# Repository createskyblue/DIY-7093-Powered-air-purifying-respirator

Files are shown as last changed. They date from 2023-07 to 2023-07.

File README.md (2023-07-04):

# 佩奇和它的7093朋友 DIY 7093 PAPR

本项目将手把手教你搭建一个PAPR (动力送风过滤式呼吸器 Powered air-purifying respirator)，在保证暴力的效果同时，将成本控制在100人民币以内。

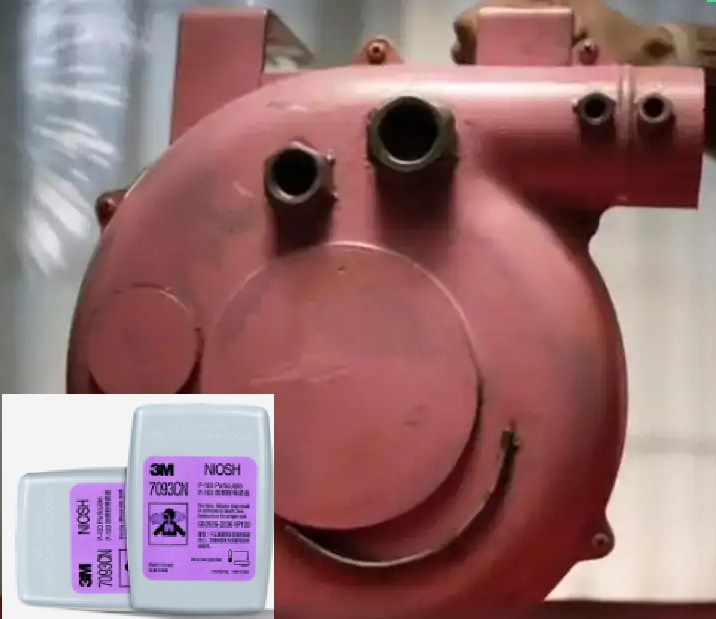
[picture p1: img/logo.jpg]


## 购物清单

你需要准备以下模块`风机和调速驱动`、`外壳`、`电源`、`气管 和 转接口`、`滤网耗材`
另外你还需要一些工具，比如`钳子`、`热熔胶枪`、`热熔胶`、`AB胶`、`705硅胶`、`热风枪`(可用`电钻`替代)、`一把长一点的螺丝刀`、`电烙铁`(可选，没有也不是不行)

### 滤网耗材

- 55￥ [3M7093CN滤毒盒](https://mobile.pinduoduo.com/transac_share_goods.html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)

### 核心风机以及驱动

- 7.8￥ [日本（Nidec）无刷蜗轮风机 DC14.4V 高速 扫地机器人吸尘风机](https://item.taobao.com/item.htm?spm=a1z09.2.0.0.9c0d2e8dZHmP4H&id=718315362174&_u=32d3muenbf90)
- 3.3￥ [带驱动无刷电机PWM调速板 DC8-24V无刷直流马达调速器](https://item.taobao.com/item.htm?spm=a1z09.2.0.0.9c0d2e8dZHmP4H&id=676307415459&_u=32d3muen34d2)

### 外壳

- 7￥ [透明盖防水盒室内外监控密封盒按钮盒仪表外壳塑料弱电防水接线盒 选择规格:F2BT 158*90*65](https://mobile.pinduoduo.com/transac_share_goods.html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) （👈请自行在拼多多平台搜索）

### 电源

- [DC002/005插座 5.5-1.3 1.35 2.0 2.1 2.5MM针DC电源充电接口母座: 购买一个](https://item.taobao.com/item.htm?spm=a21n57.1.0.0.4cd6523cXdlo5y&id=596616901501&ns=1&abbucket=0#detail)

- [DC电源线维修常用1米带线DC头 你需要购买两条规格不同的线，分别为`3.5X1.35` 和 `5.5X2.5/5.5X2.1`](D41729%26_wvx%3D10%26goods_share_id%3D2dae7d7162ddb39b16dcfcba66373f1e-3173614626821-468%26ordshr_page_sn%3D16999%26ordshr_entrance%3D1%26ordshr_page_el_sn%3D422363%26re_style%3Dtrue%26refer_share_id%3Dsma7jzfm31iuyaoho817l8i5vo41ig4b%26refer_share_uin%3D5ZL32O7MXE7ME6VAG3M3YTQVTA_GEXDA%26refer_share_channel%3Dmessage&_x_share_id=sma7jzfm31iuyaoho817l8i5vo41ig4b&refer_page_name=transac_share_goods&refer_page_id=889990_1688379440755_fuu6cvkwks&refer)

- [12V大容量空调服电池充电宝: 购买一个](https://mobile.pinduoduo.com/transac_share_goods.html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)

### 气管 和 转接口

- [呼吸机管路鱼跃通用管道配件22mm接口: 购买一个](https://mobile.yangkeduo.com/goods.html?goods_id=31158500752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)

- [波纹管接口 塑料软管接头 规格为：AD21.2 M20X1.5 购买两个，用于连接气管的两端](https://mobile.pinduoduo.com/transac_share_goods.html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)

#### 3M转接口现成方案（推荐）
- 8.8￥ [6200防毒面具喷漆防尘口罩5n11滤棉煤矿浓烟粉尘化工活性炭面罩]
https://mobile.pinduoduo.com/transac_share_goods.html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

#### 自己打印3M转接口（不推荐）
    自己打印的话容易出现各种问题，比如剪切力不过关，很容易拦腰折断；又或者气密性有问题。总之，如果你没有一定的3D打印经验，我不推荐你自己打印接口。

- [3M吸气阀片382 383 6893 6895呼吸阀3200 6200 7502面罩使用阀片: 6895垫圈 购买两个](https://item.taobao.com/item.htm?spm=a1z09.2.0.0.2ea82e8dwzGkS1&id=673407766279&_u=l2d3muen11c7)

## 3D模型
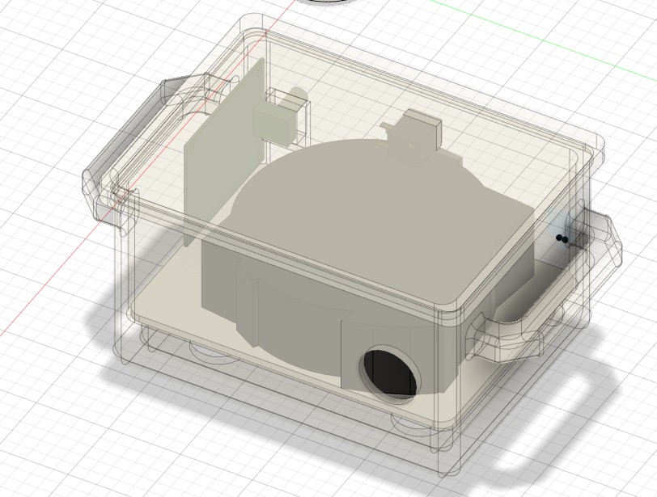
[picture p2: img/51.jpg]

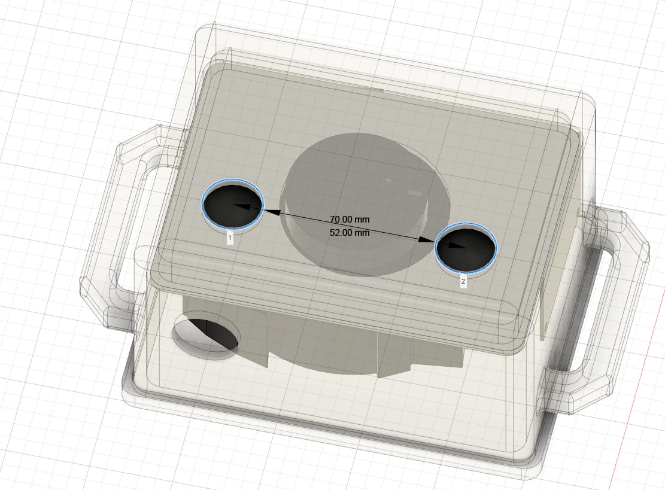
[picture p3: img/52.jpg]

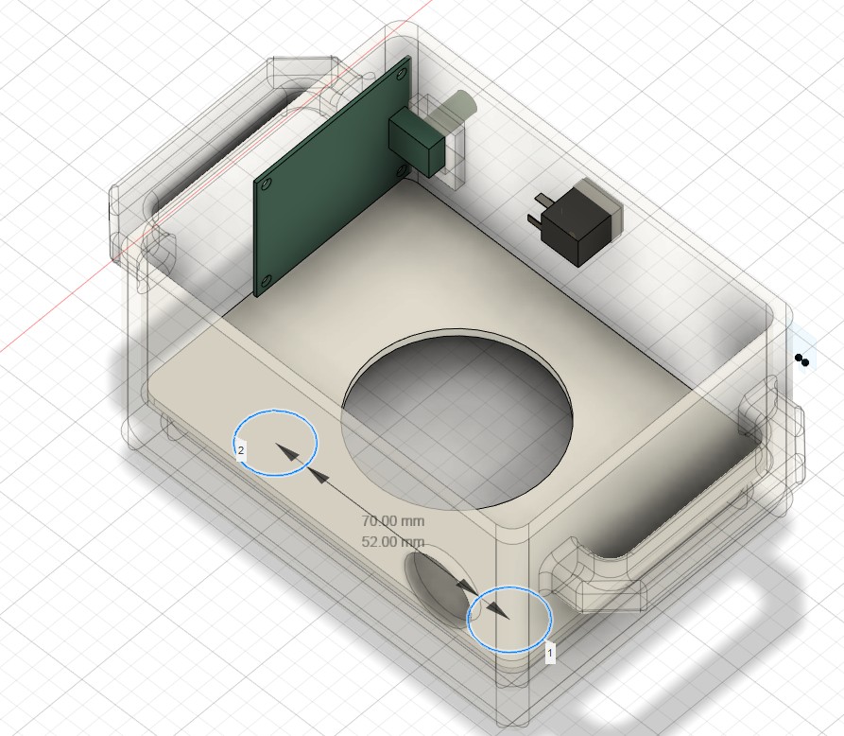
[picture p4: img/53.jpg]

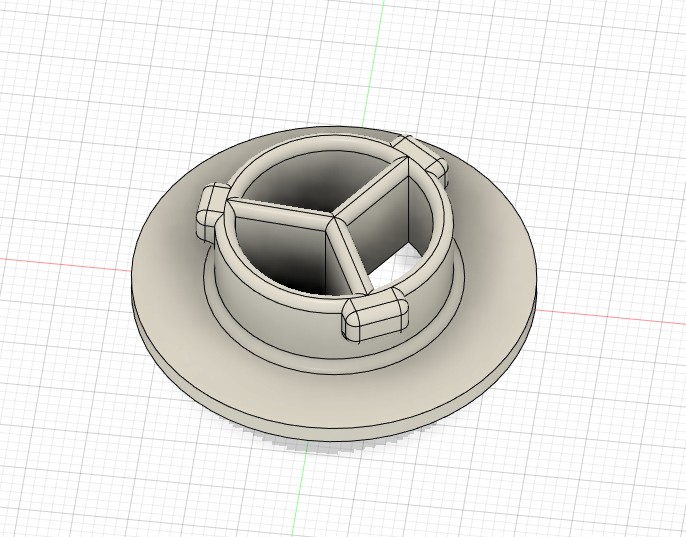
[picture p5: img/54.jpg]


## 注意事项，动手前必须阅读

- 不应该用热熔胶固定外部的接口，比如固定3M接口、22mm接口、DC接口。酒精很容易让其失效，并且强度不行
- DC005母座的金属引脚位置不是密闭的，它会渗水，更会漏气，必须要做好密封处理
- 旋钮会漏气，内部部分需要打胶
- 防水壳赠送的密封胶条在内部负压下也会渗水，更会渗气，需要打硅胶
- 组装时，先打胶再放组件。如果先放组件再打胶，会有死区打不到胶，导致很难排查的渗水和漏气
- 组装好后强烈建议进行渗水试验，方法如下：插电开机，出气口朝下，电源和旋钮朝上，7093朝向正面略微斜向上，出气口接22mm风管将气体引到远处，旋钮开至最大档，然后用水杯从上方处倒水（此步骤用充电宝供电，严禁市电），从7093面的透明顶盖向内观察是否渗水，建议重复数次。如果没有任何渗水，继续进行下一步，将出风口连接到导管并导入几厘米的水下，用力压两个7093滤盒，此时如果出风口没有气泡出现，则说明气密性试验成功。如果你的7093不小心进水，并且出风量大幅减小，不用害怕，开最小档风干即可。
- 建议每次使用前和使用后对出风口进行空气颗粒计数器的检测，确保过滤效率达标
- 本教程作者不对本教程负责，不提供任何形式的担保，本教程描述的装置不可替代医疗设备使用。如果操作或者使用的过程中出现失误受伤、感染病毒、甚至导致死亡，本文作者不担负任何责任。继续阅读则代表你已经同意该协议。

## 胶水的使用

- 目前我使用ab胶打底固定接口，等干了后最上层再灌注一层705硅胶，因为发现ab胶有异味
- 内部PCB电路板建议也打上705硅胶
- 用硅胶替代防水盒胶条，因为胶条还是会漏气

## 组装过程

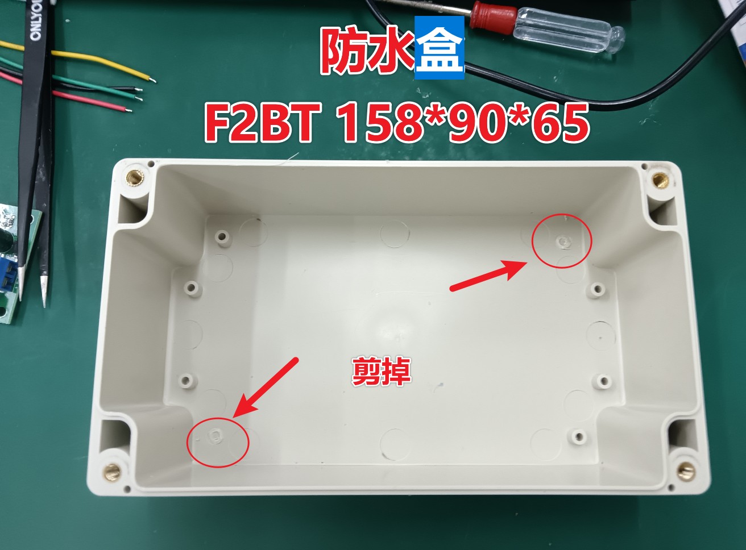
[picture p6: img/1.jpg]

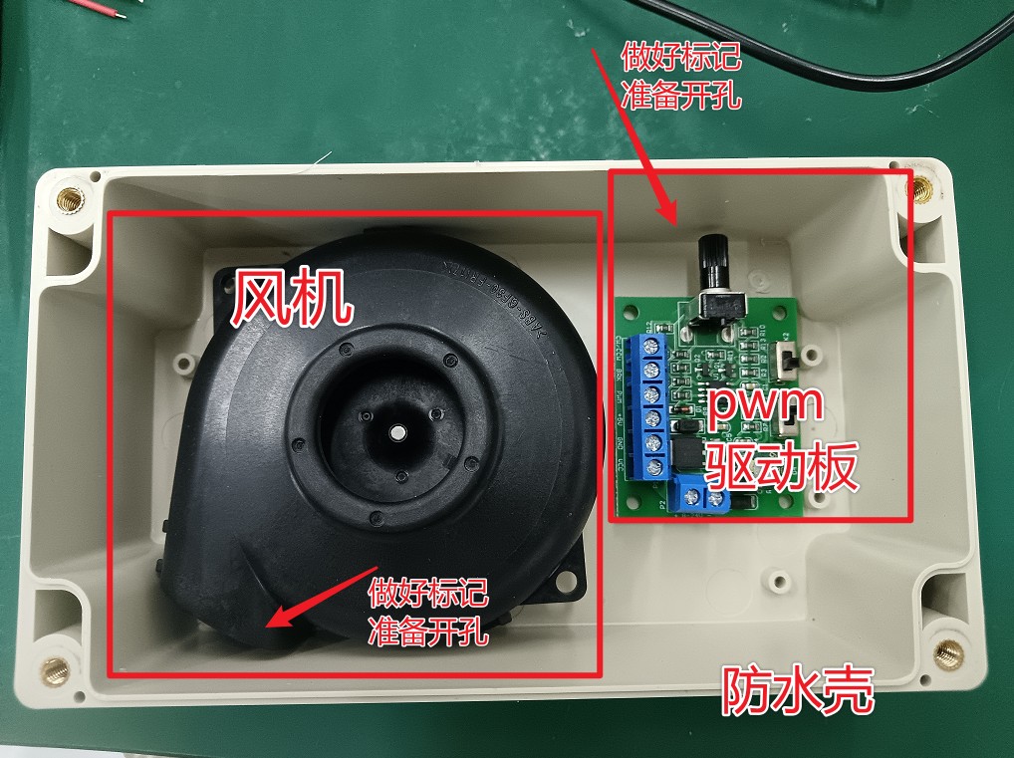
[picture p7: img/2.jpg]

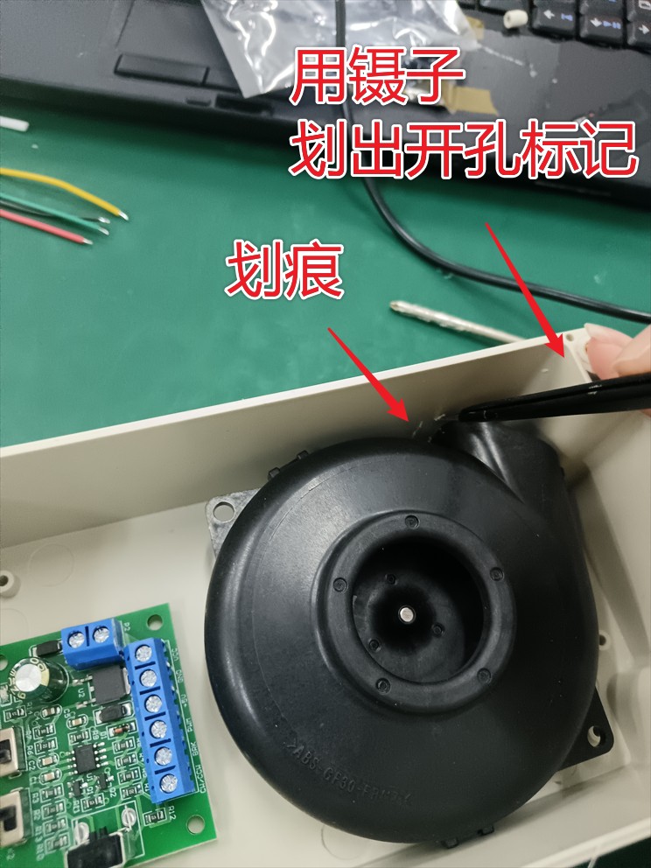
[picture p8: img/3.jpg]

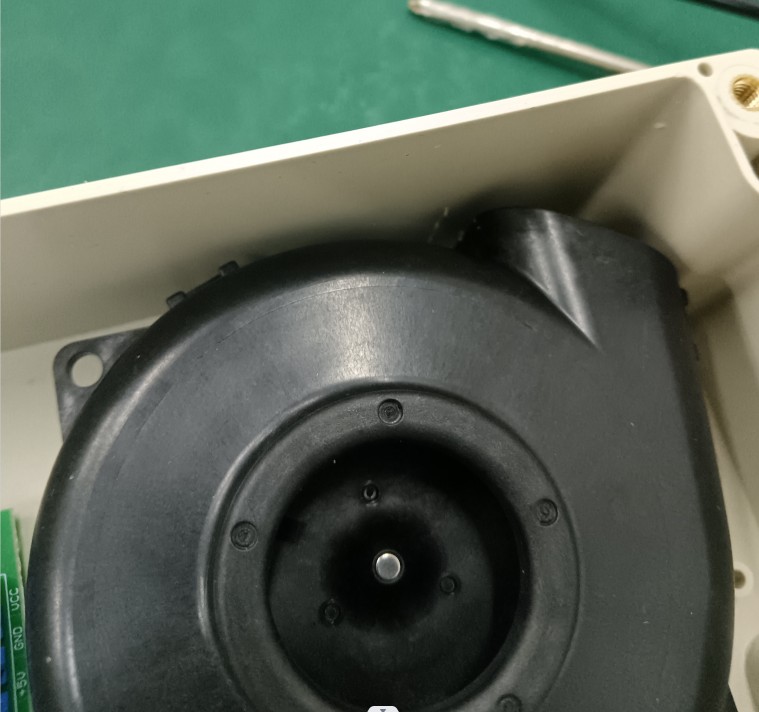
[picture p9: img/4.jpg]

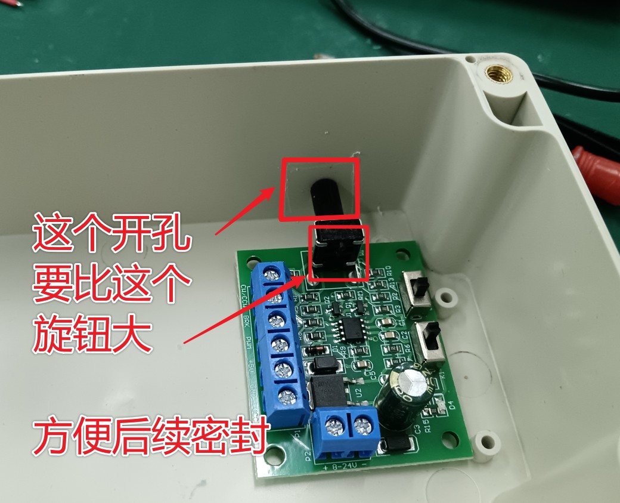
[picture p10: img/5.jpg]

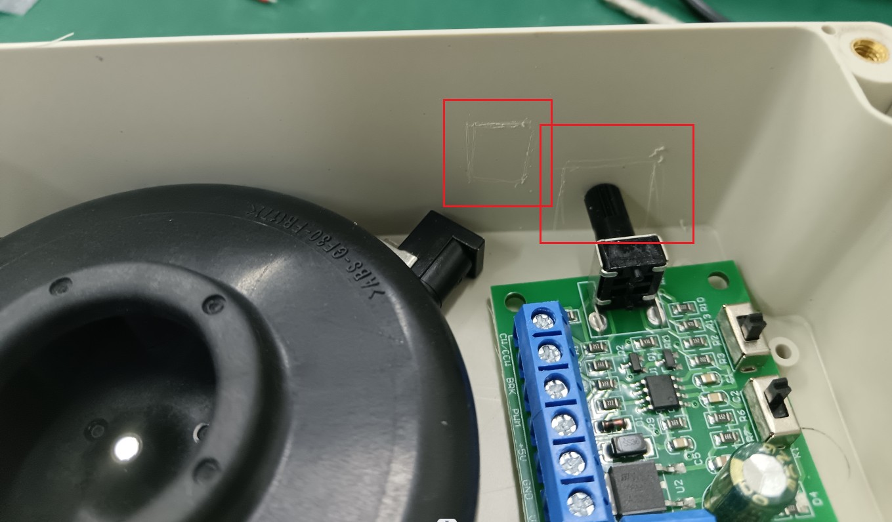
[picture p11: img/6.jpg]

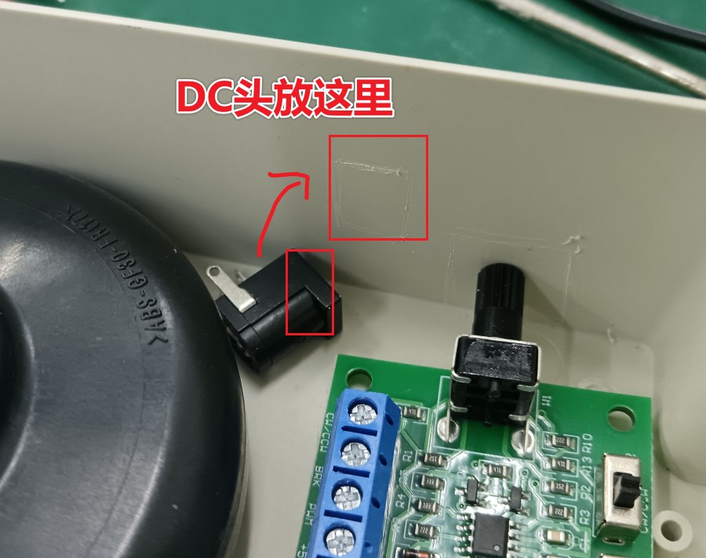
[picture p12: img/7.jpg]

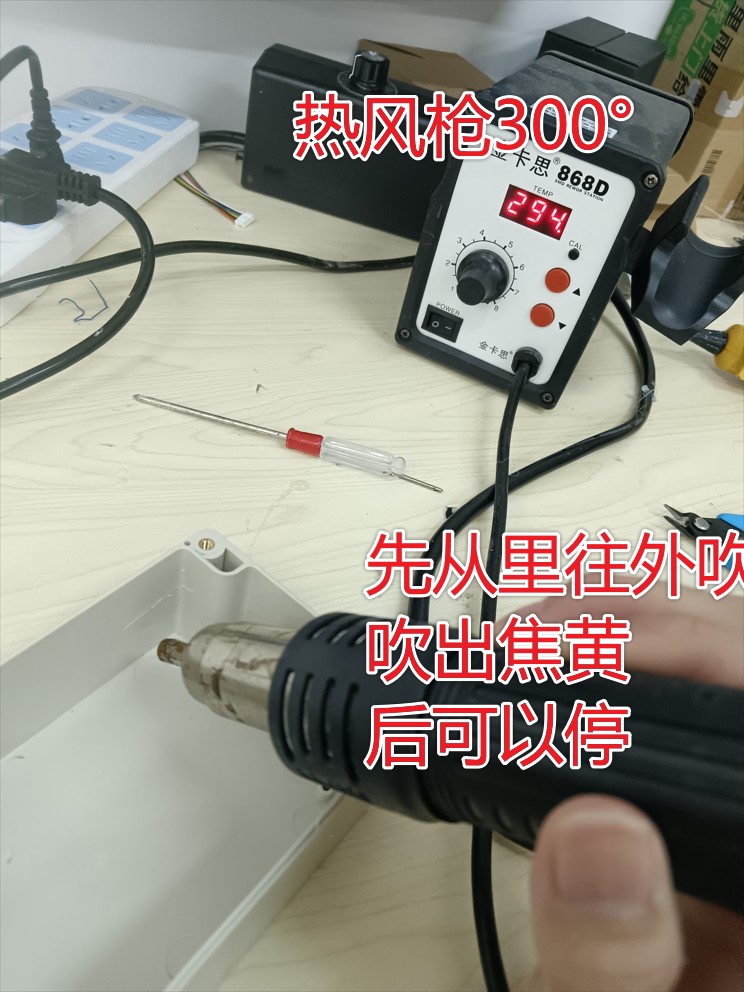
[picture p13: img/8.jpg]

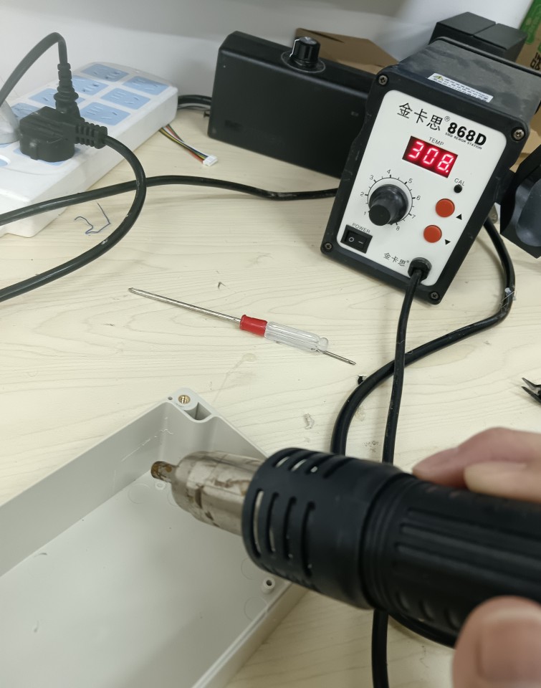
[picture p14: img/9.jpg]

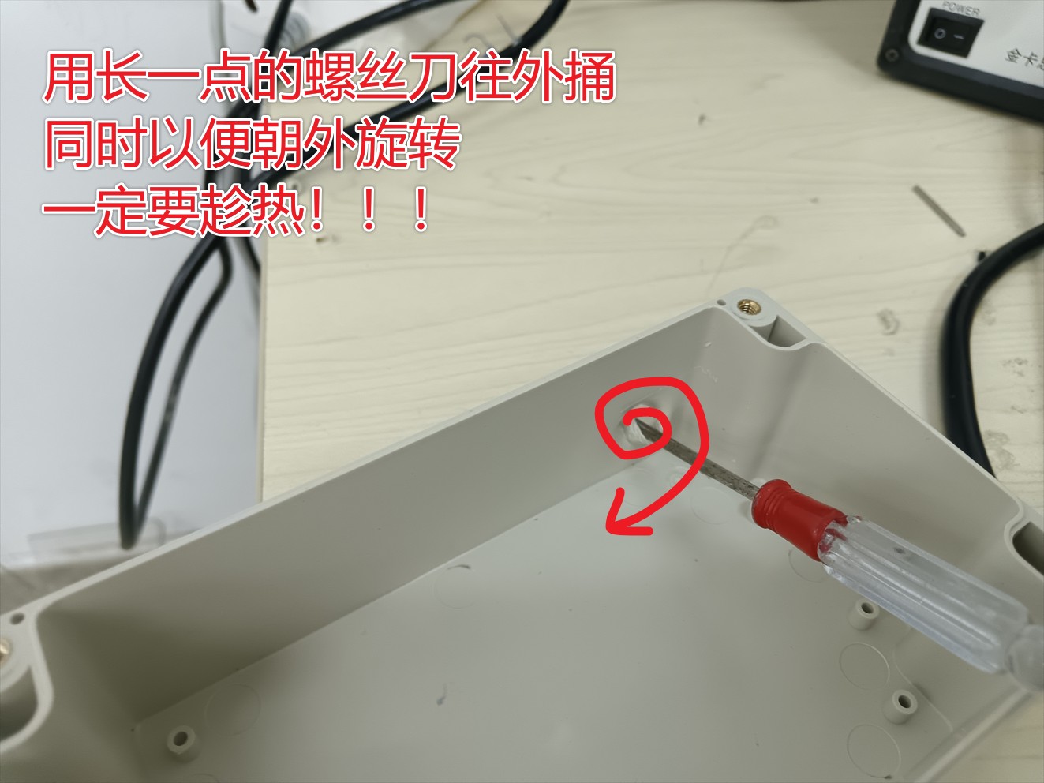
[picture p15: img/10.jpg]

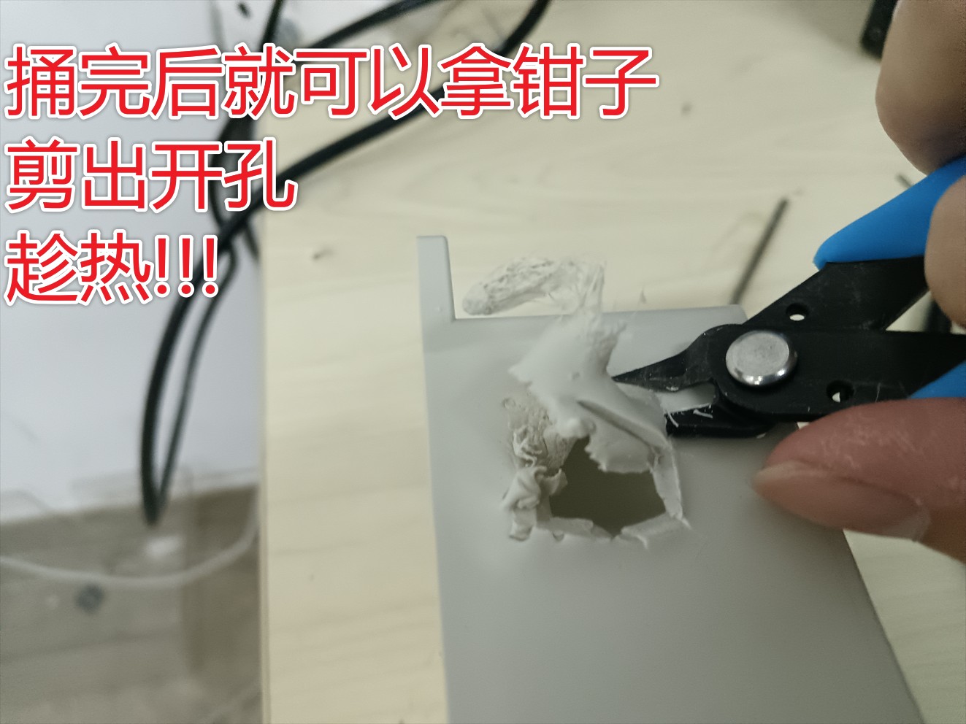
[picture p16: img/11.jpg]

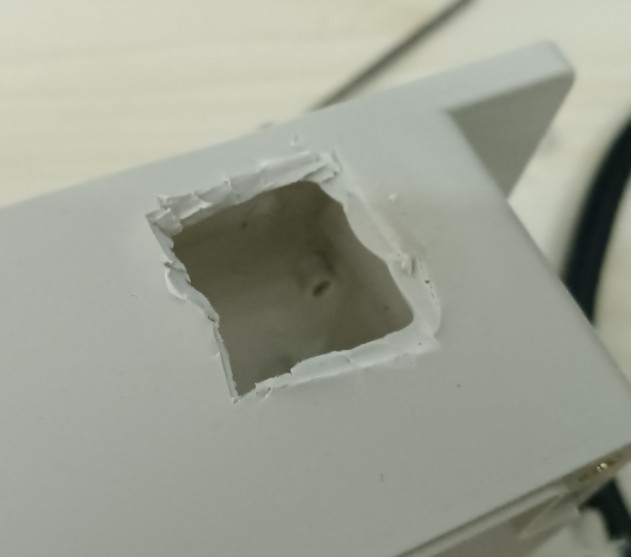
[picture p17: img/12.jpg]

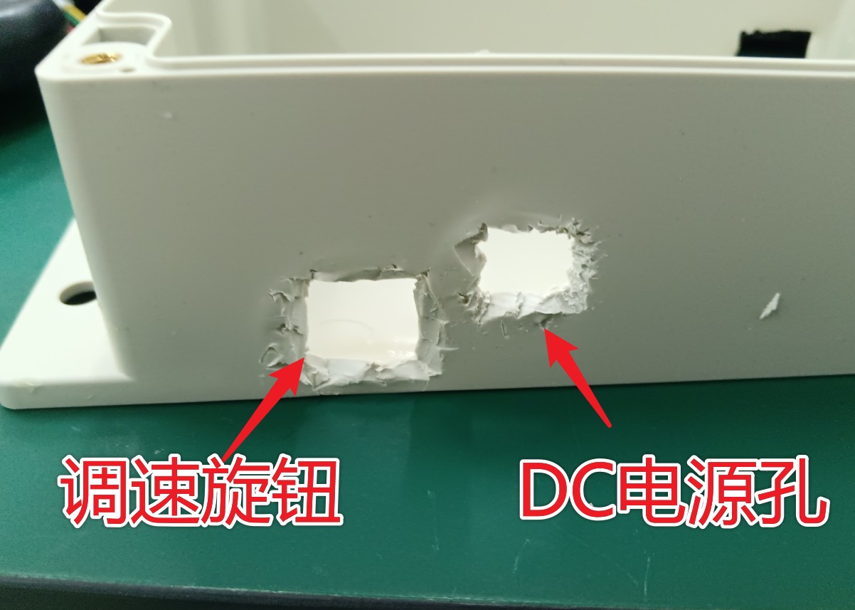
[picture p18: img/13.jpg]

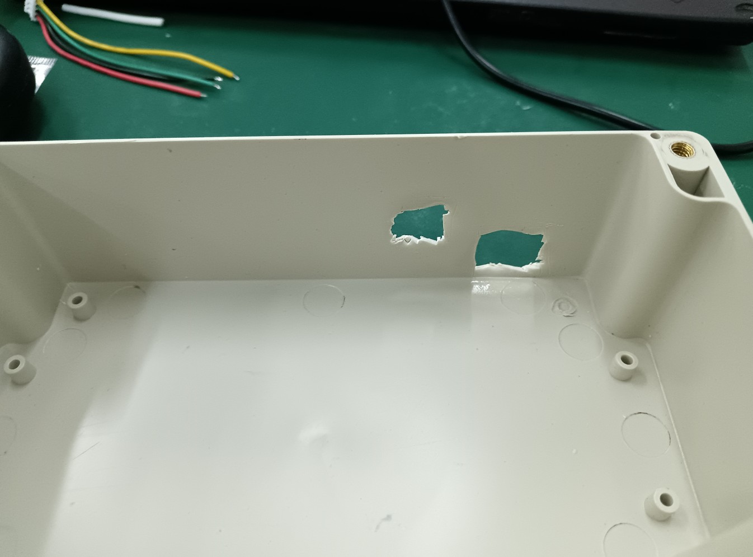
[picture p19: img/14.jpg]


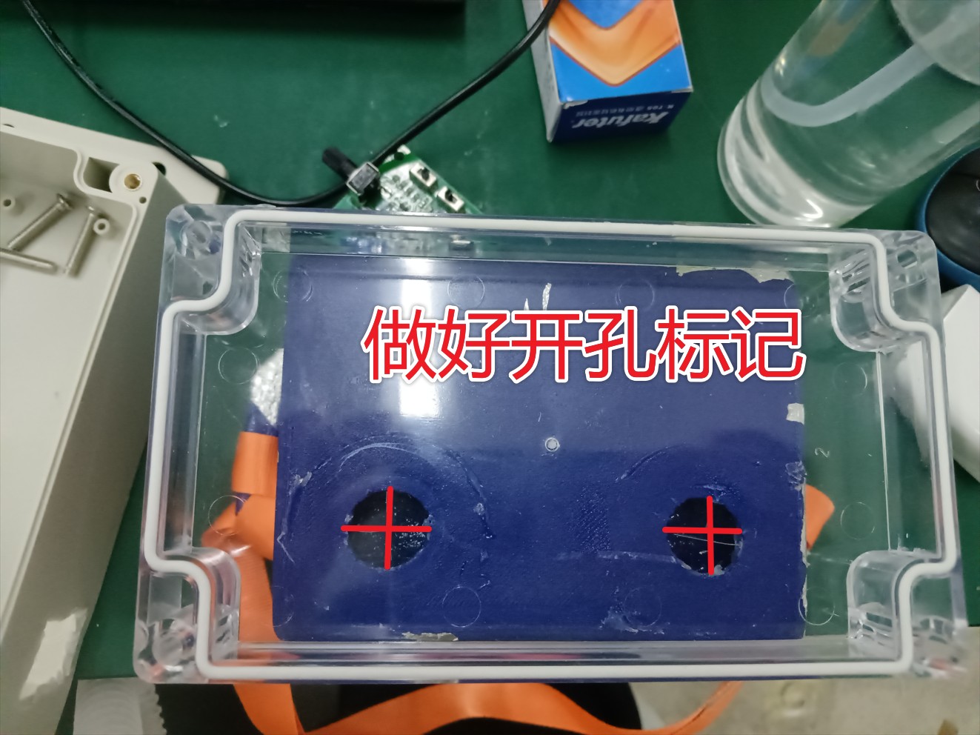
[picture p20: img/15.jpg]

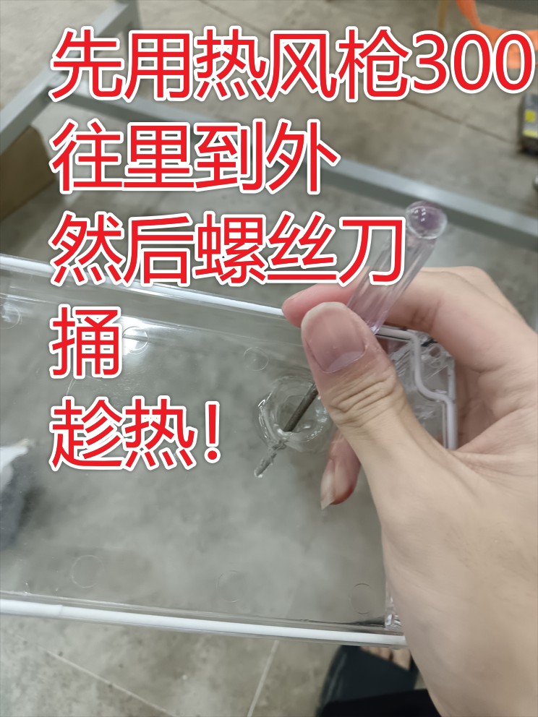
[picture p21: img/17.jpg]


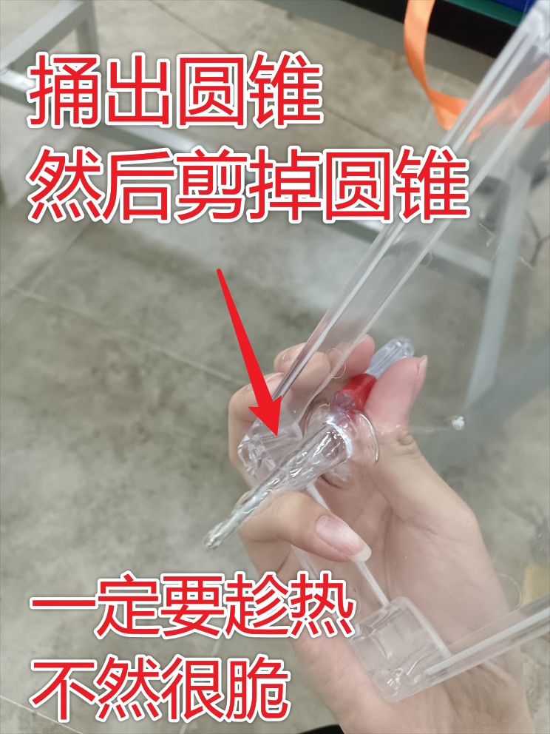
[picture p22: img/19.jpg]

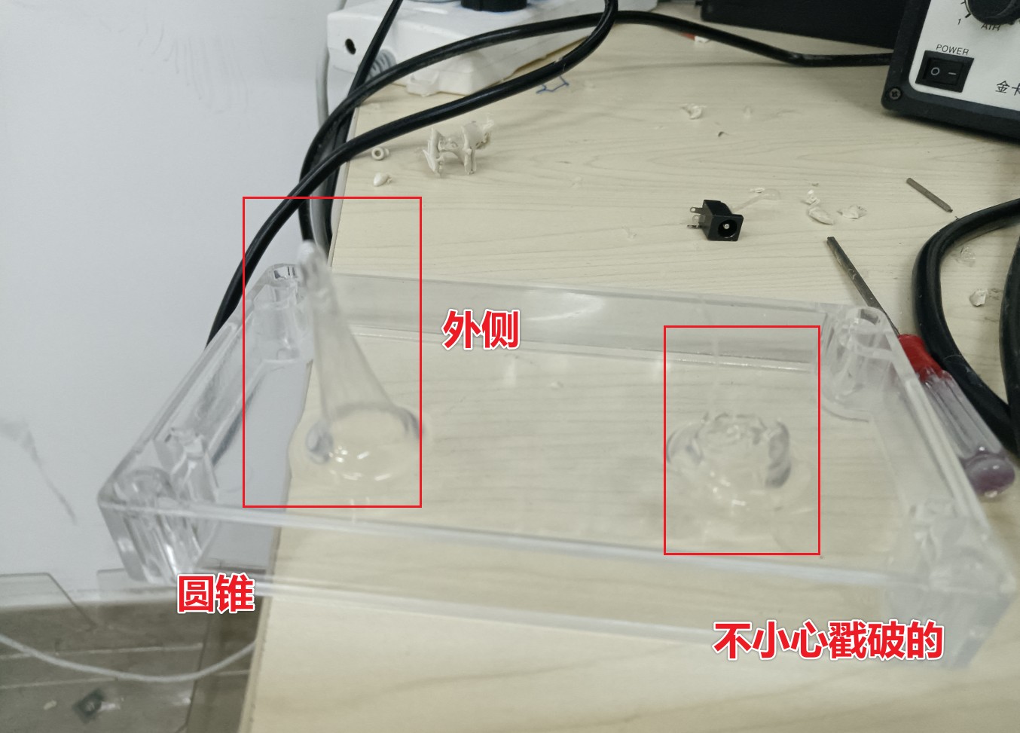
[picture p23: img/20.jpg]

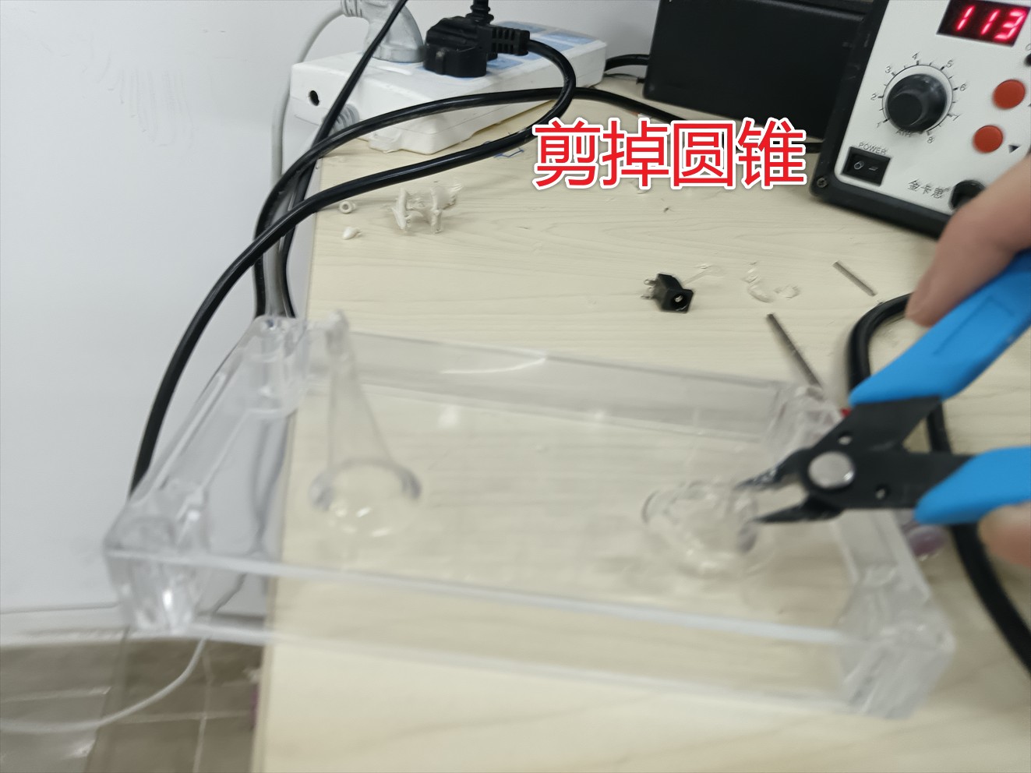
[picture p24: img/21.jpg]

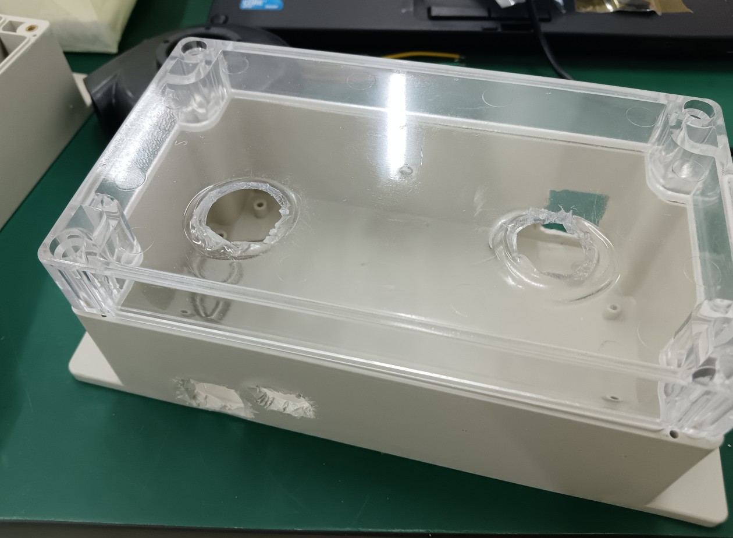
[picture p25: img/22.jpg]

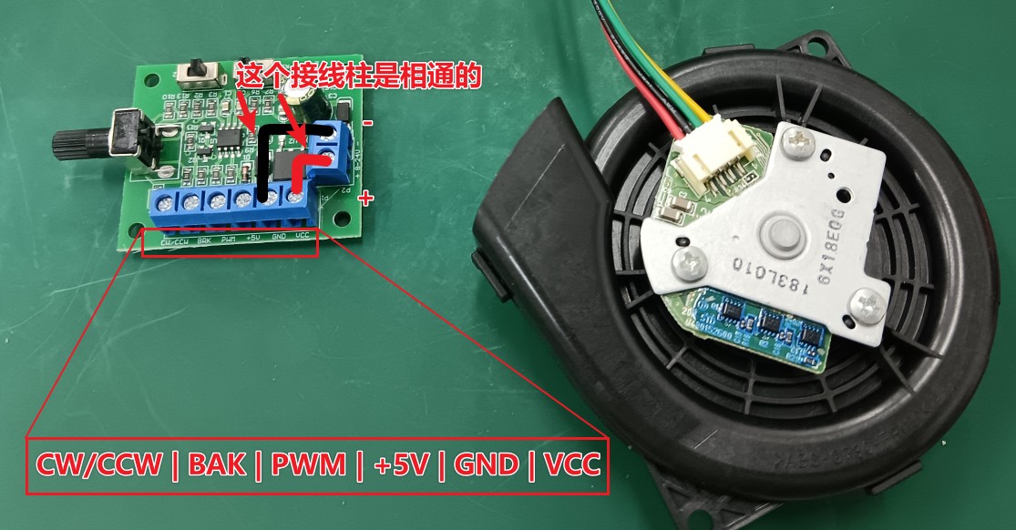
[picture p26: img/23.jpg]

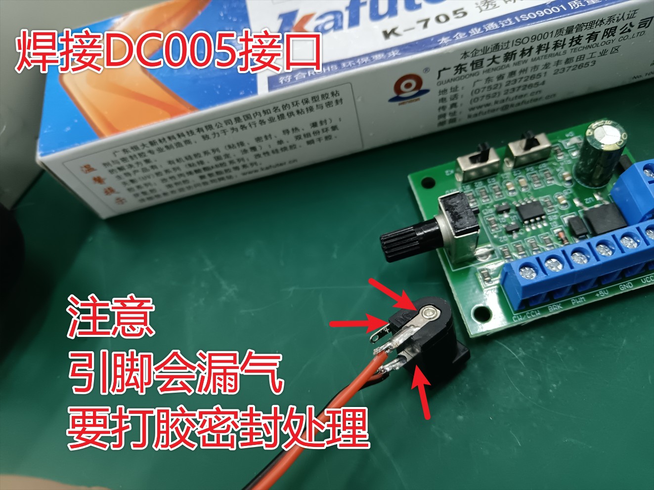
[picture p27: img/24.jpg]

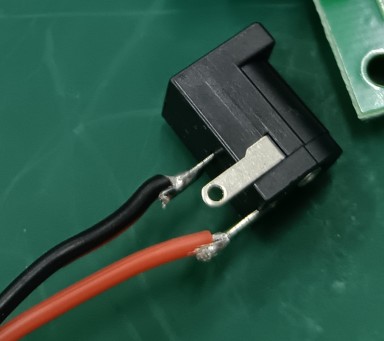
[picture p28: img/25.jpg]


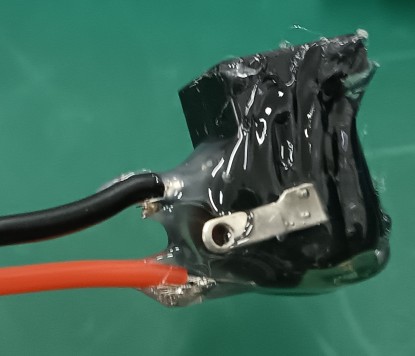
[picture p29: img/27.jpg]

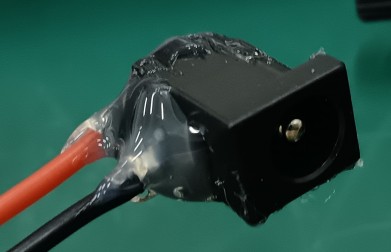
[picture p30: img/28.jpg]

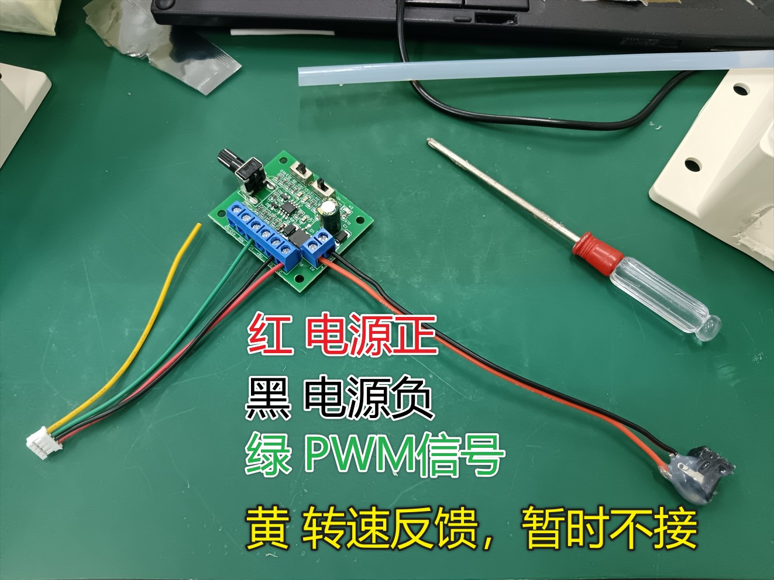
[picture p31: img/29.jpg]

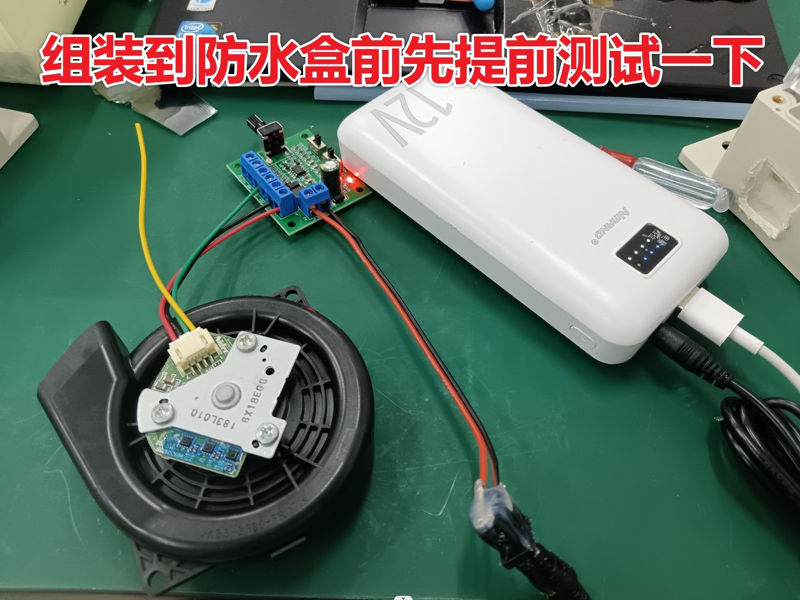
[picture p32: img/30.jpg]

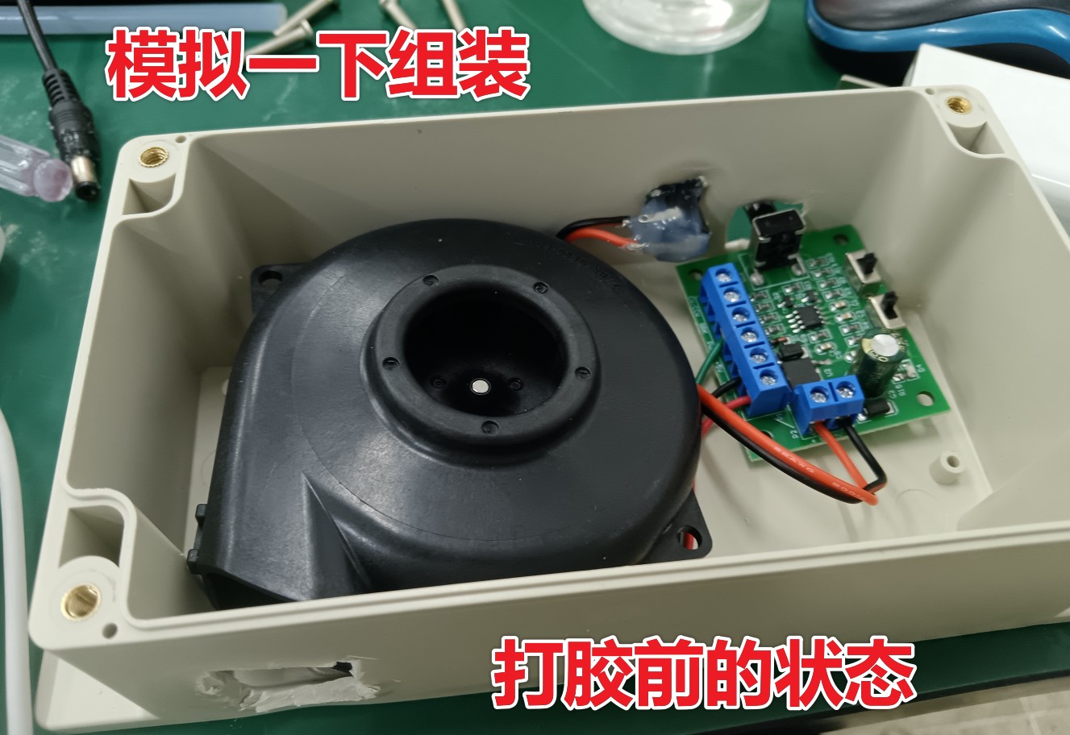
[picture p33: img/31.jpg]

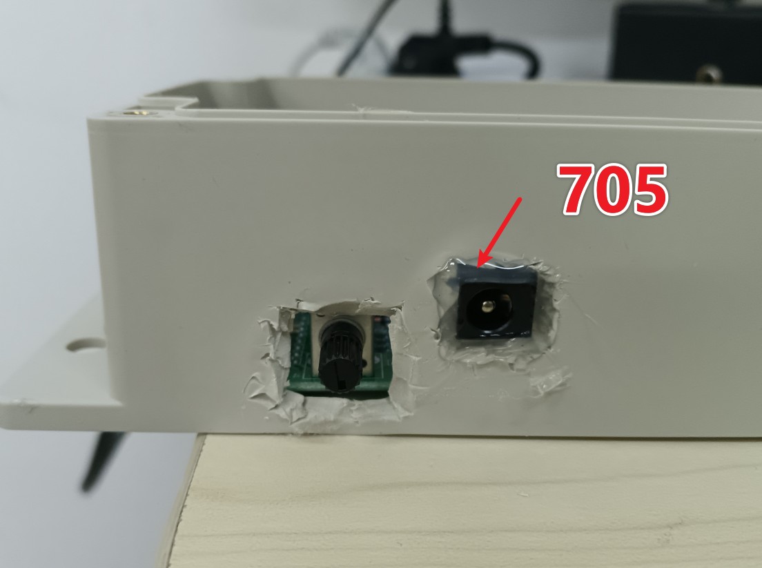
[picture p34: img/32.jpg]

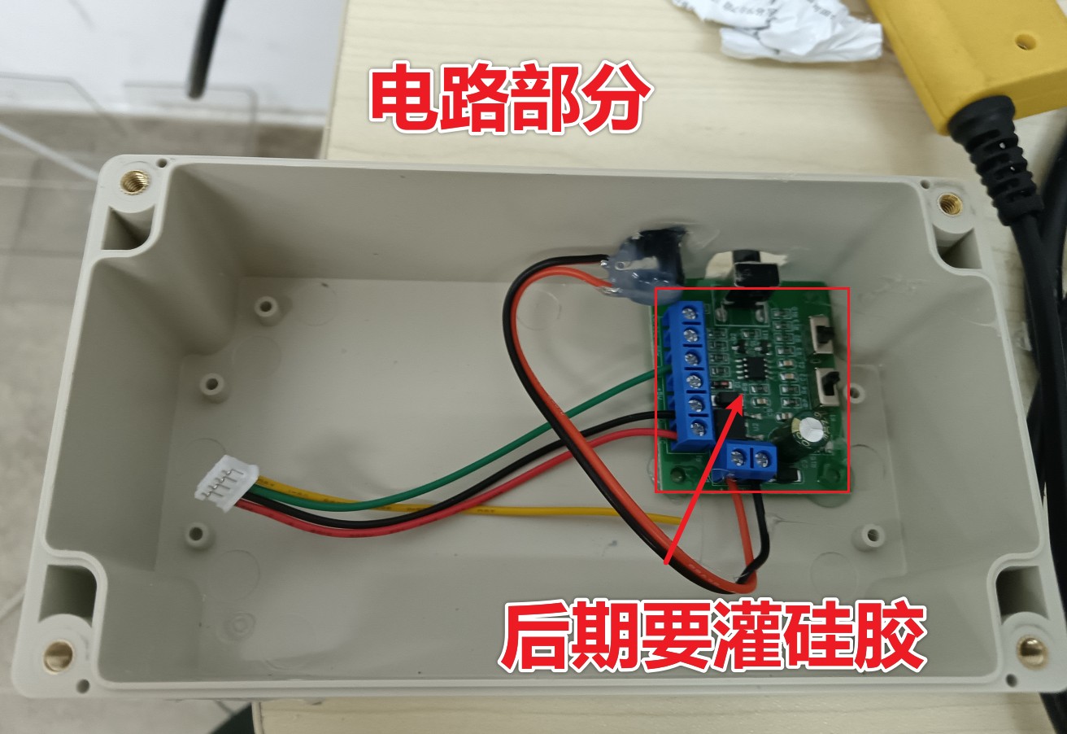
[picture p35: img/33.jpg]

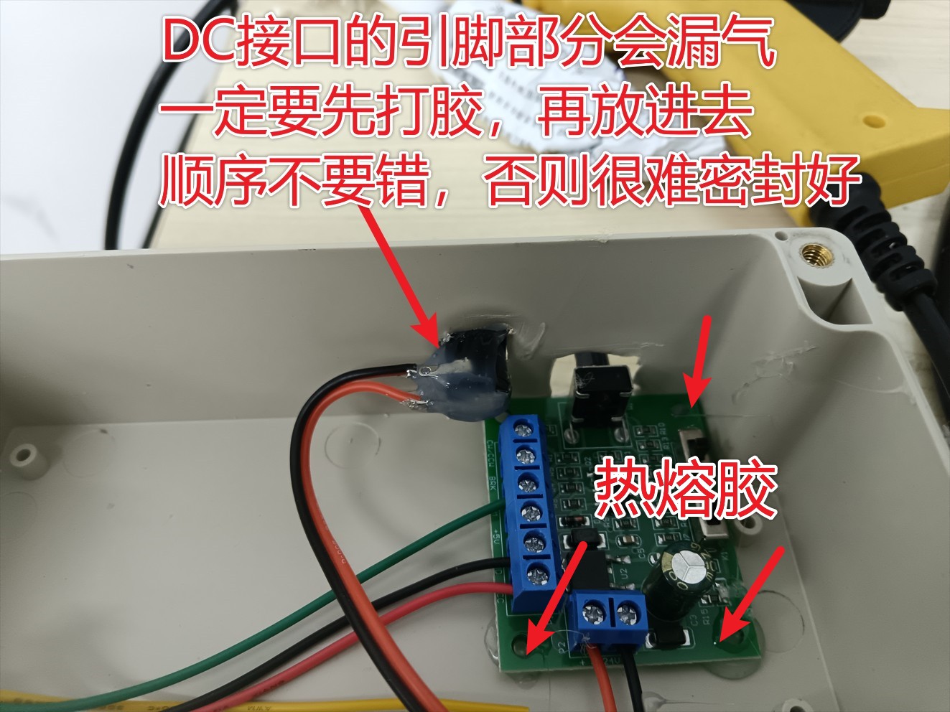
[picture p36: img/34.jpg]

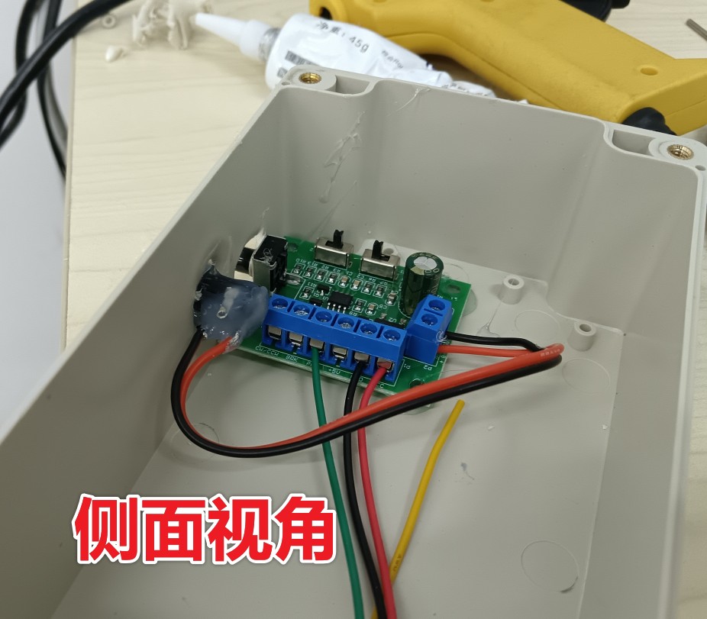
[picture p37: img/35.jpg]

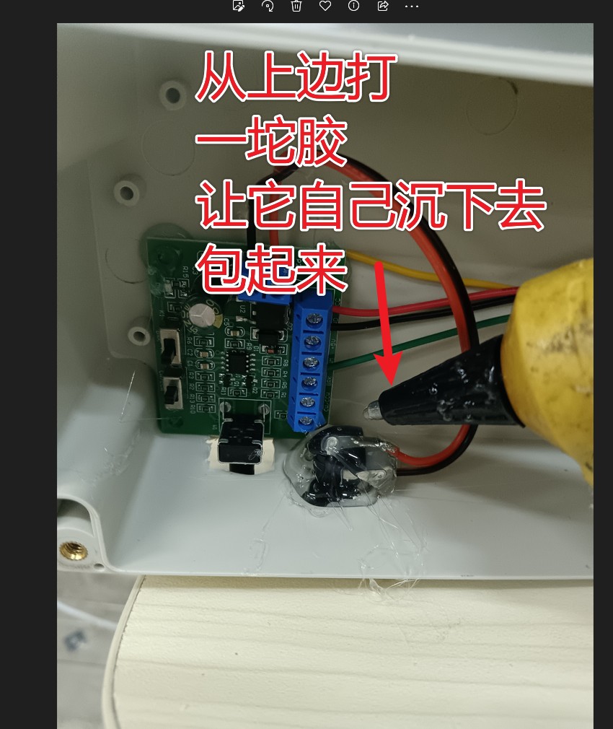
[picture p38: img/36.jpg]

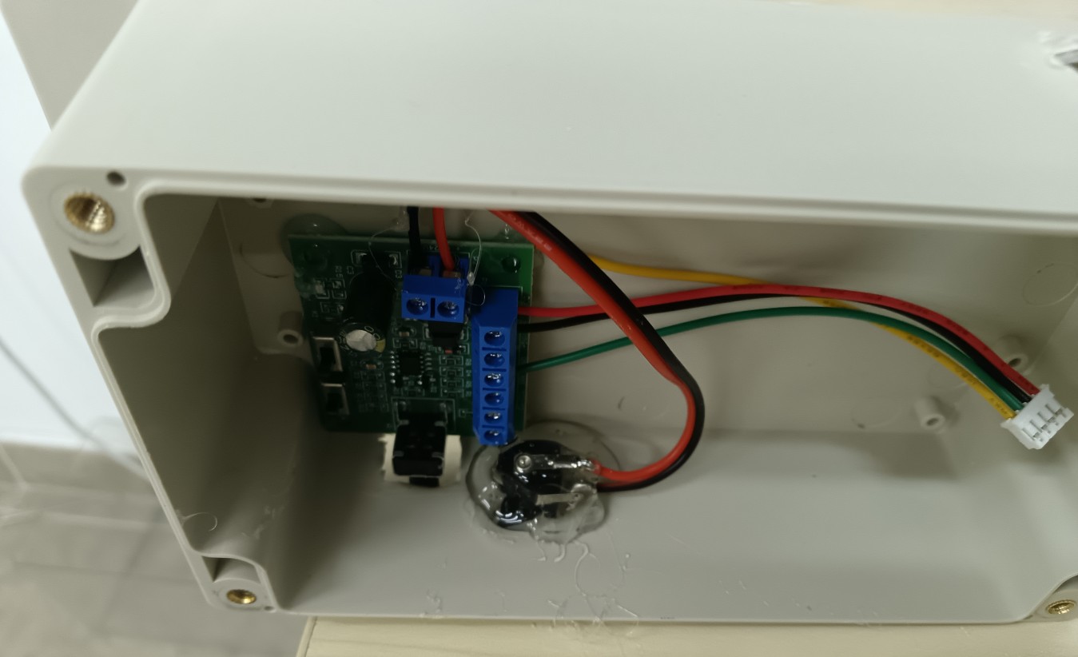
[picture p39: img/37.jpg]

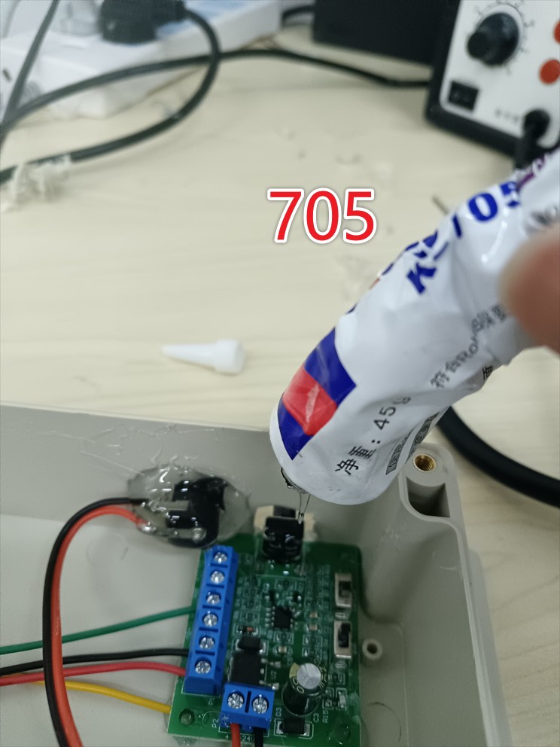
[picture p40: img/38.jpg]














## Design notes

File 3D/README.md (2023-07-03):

# 佩奇papr和她的7093朋友们

## 3D打印须知

3M接口 公头.stl 需要打印2份

22mm出气口.stl 需要打印1份 （来自 “德馨papr（极简版）”项目，非本项目原创）

顶盖.stl 需要打印1份

佩奇隔层.stl 需要打印1份

主体.stl 需要打印一份

## 问题反馈

遇到问题欢迎反馈
createskyblue@outlook.com

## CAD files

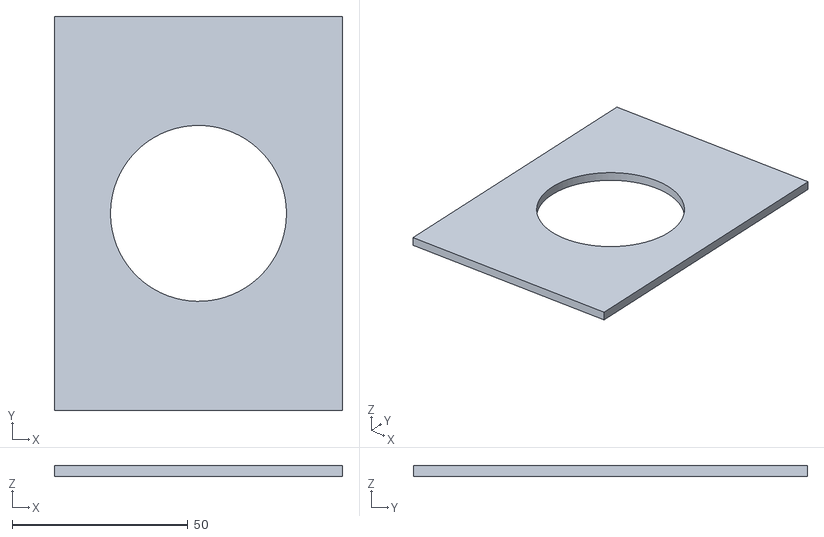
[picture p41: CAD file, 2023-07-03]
3D/佩奇隔层.stl
82.0 x 112.0 x 3.00

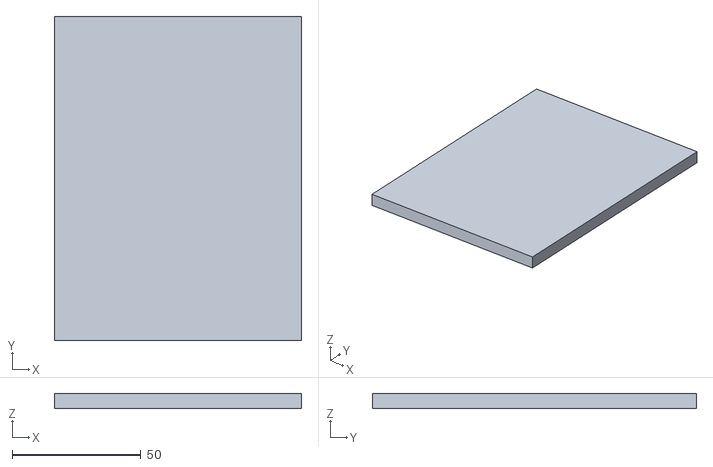
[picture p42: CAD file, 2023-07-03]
3D/顶盖.stl
96.0 x 126.0 x 6.00

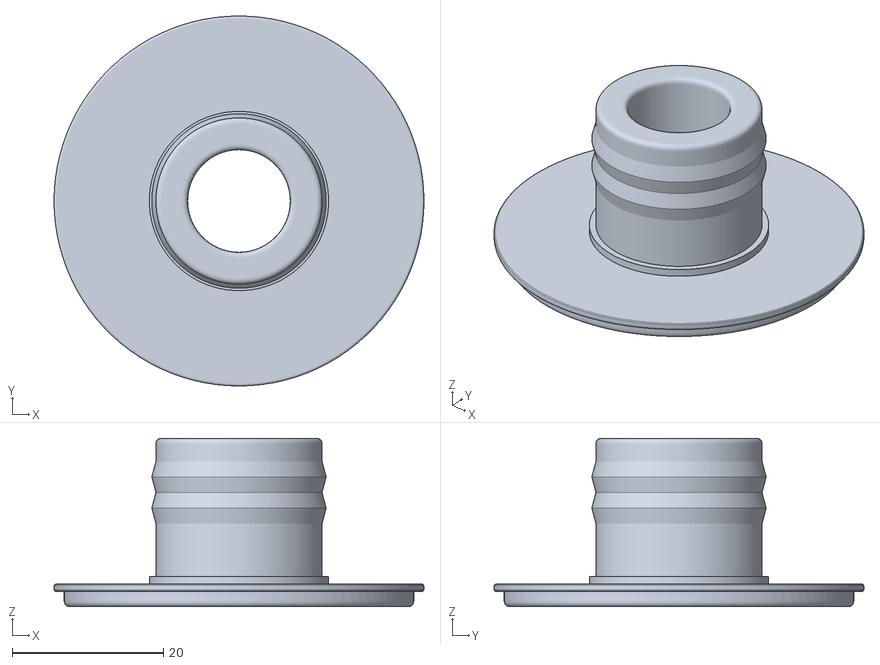
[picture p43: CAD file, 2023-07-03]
3D/22mm出气口.stl
49.0 x 49.0 x 22.3

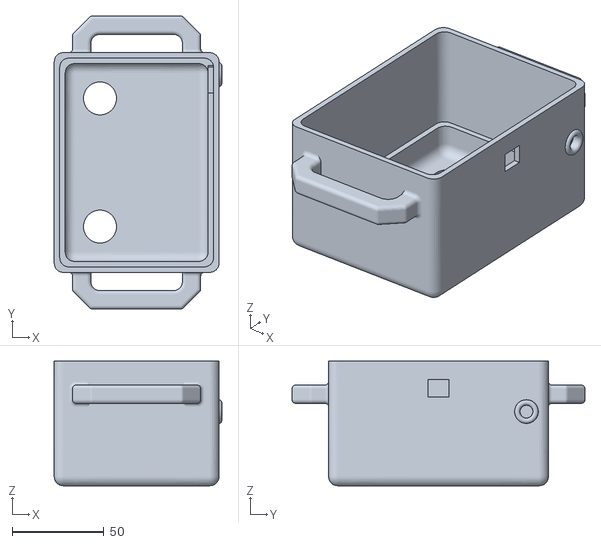
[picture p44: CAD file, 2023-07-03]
3D/主体.stl
91.5 x 160.0 x 68.0

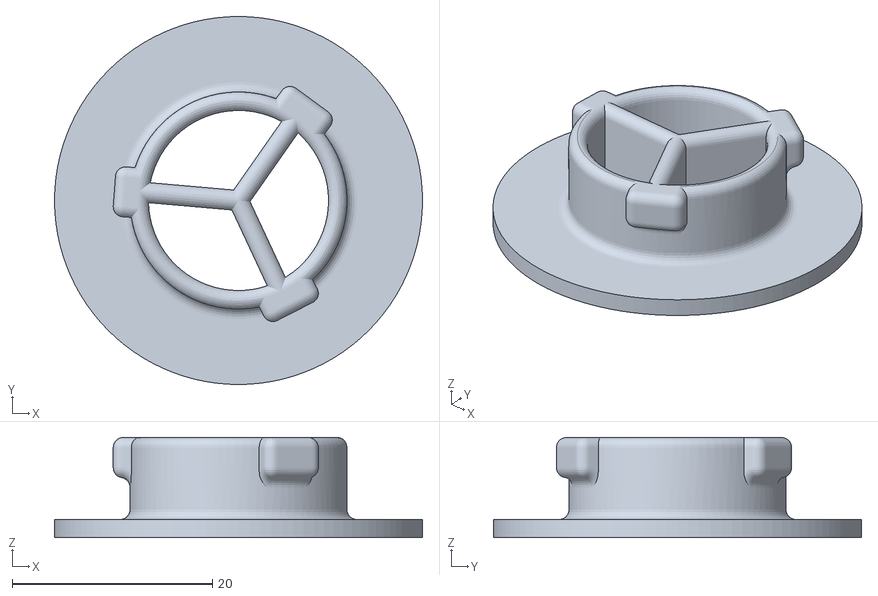
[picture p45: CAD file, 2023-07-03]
3D/3M公头.stl
36.8 x 36.8 x 10.0

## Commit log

2023-07-03 首次提交
2023-07-03 更新图片标注，使用事项
2023-07-03 增加3D模型
    [22mm出气口.stl, 3M公头.stl, 主体.stl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]
2023-07-03 修正README笔误;删除copilot提示词;增加3D模型图片;标注3M接口开口间距
2023-07-04 更新`胶水的使用`
